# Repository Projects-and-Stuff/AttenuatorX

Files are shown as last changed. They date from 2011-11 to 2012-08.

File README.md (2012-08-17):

# AttenuatorX and AttenuatorXLE #
#### Wide-Band, Large Attenuation, Medium Power, Digitally Adjustable RF Attenuators ####

This project grew out of dissatisfaction for products currently on the market. As part of my job as a Radar Technician, I needed an attenuator that could handle up to around 40 dBm, provide a variety of attenuation levels, and operate over a large frequency spectrum. The only devices I found that met these needs cost over $2000, and are adjusted physically over 1 dB increments. I thought I could do better, so I started working on doing just that. Please feel free to join me if you're interested by forking my project and requesting a merge for any improvements you add.

---

**AttenuatorXLE** is a low-cost Digitally adjustable attenuator which will be the first of two devices developed. It will offer the following preliminary specifications:

* 10 to 41 dB Attenuation in 0.5 dB Steps
* 50 MHz to 3 GHz Operation
* Up to 36 dBm Input Power

---

**AttenuatorX** is a low-cost Digitally adjustable attenuator which will be the first of two devices developed. It will offer the following preliminary specifications:

* 10 to 95 dB Attenuation in 0.5 dB Steps
* 50 MHz to 3 GHz Operation
* Up to 45 dBm Input Power

---

*File Structure*

* ./AttenuatorX/ --> Kicad Project for AttenuatorX RF Hardware
* ./AttenuatorXLE/ --> Kicad Project for AttenuatorXLE RF Hardware
* ./AttenuatorX Controller/ --> Kicad Project Controller for both RF Boards
* ./Firmware/ --> Firmware for both projects (Written in C Utilizing AVR Studio 5 and AVRGCC)
* ./Notes/ --> Project Notes, BOM, and Research on Attenuation and attenuators

---

Additional information, research, and notes can be found at http://www.projectsandstuff.com, or email us at support@projectsandstuff.com

Let us know if you fork and make improvements. We'd be glad to consider merges that improve this project.

---

UPDATES:
All updates can be found in the Project Log, within the Notes folder.

---

CURRENT AUTHORS:

> [Jack Linke](http://www.jacklinke.com)
jacklinke@gmail.com

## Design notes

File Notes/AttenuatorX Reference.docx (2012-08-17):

Projects and Stuff

AttenuatorX

In-Depth Reference

# Overview and Objectives

# Assemble

## Part List

## Tools Required

## Constructing it

# Operate

# Mod

# Buy

# Discuss

# Schematics

# Source Code

## Source Code Overview

## Libraries Used

## Functional Description

Glossary

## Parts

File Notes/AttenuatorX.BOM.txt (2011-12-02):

\\\\\\\\\\\\\\\\\\\\\\\\\\\\\\\\\
/////////////////////////////////
\\\\\\\\\\\\\\\\\\\\\\\\\\\\\\\\\
Bill of Materials for AttenuatorX
/////////////////////////////////
\\\\\\\\\\\\\\\\\\\\\\\\\\\\\\\\\
/////////////////////////////////

SPDT RF Switches

SKY13268-344
http://search.digikey.com/us/en/products/SKY13268-344LF/863-1047-1-ND/2052179
Freq Range: 300kHz-3GHz
Max Input Power: 37.8dBm (6 W)
Insertion Loss: 0.4dB
Isolation: 25dB
Qty: 
U/P: $0.53
T/P: $

RF3025
http://www.rfmw.com/ProductDetail/RF3025/392839
RF Switch, SPDT
Frequency Min: 0.01 GHz 
Frequency Max: 6 GHz 
Insertion Loss Range: 0.5 dB 
Isolation Range: 58 dB 
Power Rating: 27 dBm (0.5 W)
U/P: $2.00 (x25)

FMS2031-001
http://www.rfmw.com/ProductDetail/FMS2031001/319867/
https://estore.rfmd.com/RFMD_Onlinestore/Products/RFMD+Parts/PID-P_FMS2031-001.aspx?DC=25
10W GaAs pHEMT SPDT Switch
Frequency Range (Min) (MHz):  0 
Frequency Range (Max) (MHz):  6000 
Insertion Loss (dB):  0.5 
Isolation (dB):  32 
Max Power: 39-41 dBm (7.9-12.5 W)
U/P: 25 @ $3.03 EA

SP4T RF Switches

PE42641MLIBB-Z
http://search.digikey.com/us/en/products/PE42641MLIBB-Z/1046-1013-1-ND/2614517
Freq Range: 0-3 GHz
Max Input Power: 38dBm (6.3 W)
Insertion Loss: 0.45dBm
Isolation: 43dB
Qty: 
U/P: $2.77
T/P: $

Step Attenuator Chain:

TQP4M9072
http://www.mouser.com/ProductDetail/TriQuint-Semiconductor/TQP4M9072/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
Freq Range: 0-4GHz
LSB: 0.5dB
Max Input Power: 28dBm (0.6 W)
Insertion Loss: 1.5dB
Accuracy: 0.3 + 3%
Max Attenuation: 31.5dB
Qty: 
U/P: $4.18
T/P: $

-------------------

HMC629LP4 / 629LP4E
http://www.hittite.com/products/view.html/view/HMC629LP4
http://www.hittite.com/shop/product.php?productid=1403
Freq Range: DC-6GHz
LSB: 3 dB
Max Attenuation: 45 dB
Input Power: 28 dBm (0.6 W)
Insertion Loss DC - 6: 2.5 dB
Accuracy: 0.50 + 5% of Atten. Setting
$9.75 OR $7.50

Fixed Attenuators:

33-1001-10.00
NO DATASHEET (requested 20111105)
http://www.rfmw.com/ProductDetail/3310011000/302627
Attenuator, Fixed
Frequency Min: 0 GHz 
Frequency Max: 4 GHz 
dB Value: 10 dB 
Power Handling: 20 W (43 dBm)
U/P: $16.98

D10AA5Z4
http://www.rell.com/Pages/Product-Details.aspx?productId=728179
Power 7 W (38.5 dBm)
Attenuation 3 dB
Frequency Max 3000 MHz
$4.34

D10AA3Z4
http://www.rell.com/Pages/Product-Details.aspx?productId=728176
Power 7 W (38.5 dBm)
Attenuation 3 dB
Frequency Max 3000 MHz
$4.34

83A399506.00F
NO DATASHEET (Requested 20111105)
http://www.rfmw.com/ProductDetail/83A39950600F/325214
Attenuator, Fixed
Frequency Min: 0 GHz 
Frequency Max: 3 GHz 
dB Value: 6 dB 
Power Handling: 5 W (37 dBm)
U/P: $12.47

ATN3590-XX
Fixed Attenuators 2W (33 dBm)
http://www.rfmw.com/Paw.aspx?type=330
Freq Range: 0-40 GHz
Attenuation: 1-40 dB
U/P: $3.00-$3.25

Need medium power 1 dB (Rated for XX W) or 2 dB (Rated for XX W) attenuators for the front end.

RF Detector:

LT5534
http://search.digikey.com/us/en/products/LT5534ESC6%23TRMPBF/LT5534ESC6%23TRMPBFCT-ND/962666
Input Range: -63dBm to -3dBm
Frequency: 50MHz ~ 3GHz
Qty: 
U/P: $10.30
T/P: $

CONN FMALE-ON-BRD 6POS VERT T/H
Connector for Encoders
P/N: 7-215079-6
http://search.digikey.com/us/en/products/7-215079-6/A30729CT-ND/740377
Pitch 0.100" (2.54mm)
Qty: 
U/P: $1.33
T/P: $

ENCODER OPT 32PPR IP65 5" CABLE
C14D32P-B3A
Quadrature Encoder with pushbutton
http://search.digikey.com/us/en/products/C14D32P-B3A/102-2034-ND/2193096
Encoder Type Optical
Voltage - Supply 5VDC
Pulses per Revolution 32
Actuator Type 1/4" Dia Flatted End
Detent Yes
Built in Switch Yes
Qty: 
U/P: $17.78
T/P: $

Long Shaft Rotary Encoder
ENCODER 11MM ROTARY SW TOP ADJ
EN11-HSM1BF20
http://search.digikey.com/us/en/products/EN11-HSM1BF20/987-1398-ND/2620667
Actuator Type: 6mm Dia Flatted End
Detent: Yes
Built in Switch: Yes
Qty: 
U/P: $1.35
T/P: $

Short Shaft Rotary Encoder
ENCODER 11MM ROTARY SW TOP ADJ
EN11-HSM1AF15
http://search.digikey.com/us/en/products/EN11-HSM1AF15/987-1188-ND/2408766
Actuator Type: 6mm Dia Flatted End
Detent: Yes
Built in Switch: Yes
Qty: 
U/P: $1.35
T/P: $

KNOB PLASTIC 1/4" DIA BLACK
Knob for encoders (can I find a better one?)
http://search.digikey.com/us/en/products/11K5014-KCNB/GH7339-ND/1534744
Qty: 
U/P: $0.65
T/P: $

BOX HANDHELD TG 4.92 X 3.15 X 1.84"
Project Enclosure
P/N: 270102110
http://search.digikey.com/scripts/dksearch/dksus.dll?vendor=0&keywords=27010211&stock=1
http://www.rose-bopla.com/Prod_Pgs/Handhelds/Prod_04_TG_130_Handheld.htm
Features Battery Door, PCB Supports
Qty: 1
U/P: $11.58
T/P: $11.58

CONN SOCKET BNC R/A 50 OHM PCB
BNC Connectors
P/N: 1-1337543-0
http://search.digikey.com/us/en/products/1-1337543-0/A97553-ND/1755940
Impedance 50 Ohm
Mounting Type Through Hole, Right Angle 
Fastening Type Bayonet Lock
Frequency - Max 4GHz
Qty: 2
U/P: $2.30
T/P: $4.60

SNAPS 9V 6" LEADS I-STYLE
9V Battery Clip
Part Number: BS6I
http://search.digikey.com/us/en/products/BS6I/BS6I-ND/32055
Qty: 1
U/P: $0.53
T/P: $0.53

LCD COG CHAR 2X16 TRANSFL
LCD (Outline L x W x H	54.70mm X 25.30mm X 5.00mm)
http://search.digikey.com/us/en/products/NHD-C0216AZ-FSW-GBW/NHD-C0216AZ-FSW-GBW-ND/2165869
Qty: 1
U/P: $10.11
T/P: $10.11

///// Trimmers for possible alignment attenuator \\\\\

TRIMMER 200 OHM 0.25W SMD
Trimmer/Potentiometer for alignment of attenuation to attenuators
P/N: SM-42TW201
http://search.digikey.com/us/en/products/SM-42TW201/SM-42TW201CT-ND/1632393
Resistance (Ohms): 200
Power (Watts): 0.25W, 1/4W
Number of Turns: 11 
Adjustment Type Top Adjustment
Qty: 
U/P: $2.79
T/P: $

TRIMMER 20 OHM 0.25W SMD
Trimmer/Potentiometer for alignment of attenuation to RF detector
P/N: 3269W-1-200LF
http://search.digikey.com/us/en/products/3269W-1-200LF/3269W-1-200LF-ND/1211542
Resistance (Ohms): 20
Power (Watts): 0.25W, 1/4W
Number of Turns: 12
Adjustment Type Top Adjustment
Qty: 
U/P: $5.64
T/P: $

TRIMMER 500 OHM 0.25W SMD
Trimmer/Potentiometer for alignment of attenuation to RF detector
P/N: SM-42TW501
http://search.digikey.com/us/en/products/SM-42TW501/SM-42TW501CT-ND/1632394
Resistance (Ohms): 500
Power (Watts): 0.25W, 1/4W
Number of Turns: 11 
Adjustment Type Top Adjustment
Qty: 
U/P: $2.79
T/P: $

///// End Trimmers \\\\\

RES 5.1K OHM 1/4W 5% 1206 SMD (3.20mm x 1.60mm)
5.1 KOhm External Pull-up Resistors for Encoder
RMCF1206JT5K10
http://search.digikey.com/us/en/products/RMCF1206JT5K10/RMCF1206JT5K10CT-ND/1942798
Qty: 1
U/P: $0.05
T/P: $0.05

CAP CER 0.3PF 50V 0603 (1.60mm x 0.84mm)
0.3 pF ±0.05pF coupling capacitor for RF Detector (to obtain ~20db loss) (qty 1)
ML03510R3AAT2A
http://search.digikey.com/us/en/products/ML03510R3AAT2A/478-6725-1-ND/2694239
Qty: 1
U/P: $0.88
T/P: $0.88

RES PREC 100 OHM 333MW .1% 1206 (3.20mm x 1.60mm)
100 Ohm +/-5% coupling resistor for RF Detector (to obtain ~20db loss)
PFC-W1206LF-03-1000-B-1059
http://search.digikey.com/us/en/products/PFC-W1206LF-03-1000-B-1059/989-1154-1-ND/2407974
Qty: 1
U/P: $0.65
T/P: $0.65

CAP CER 0.1UF 50V 10% X7R 1206
0.1 uF Ceramic Bypass Capacitor for Digital Circuitry
12065C104KAT2A
http://search.digikey.com/us/en/products/12065C104KAT2A/478-1556-1-ND/564588
Qty: 20
U/P: $0.077
T/P: $1.54

Bulk Bypass Capacitors
CAP CER 10UF 25V Y5V 1206
C3216Y5V1E106Z
http://search.digikey.com/us/en/products/C3216Y5V1E106Z/445-3469-1-ND/1801568
Qty: Multiple
U/P: $0.36
T/P: $

CAP CERAMIC 100PF 50V NP0 1206
100 pF capacitors for SPDT RF Switch DC Blocking (qty 3)
C1206C101J5GACTU
http://search.digikey.com/us/en/products/C1206C101J5GACTU/399-1205-1-ND/411480
Qty: 3
U/P: $0.31
T/P: $0.93

RES TF 15 OHM 5% 0.25W 1206
15 Ohm Pull-up resistor for TQP4M9072 Attenuator
RMCF1206JT15R0
http://search.digikey.com/us/en/products/RMCF1206JT15R0/RMCF1206JT15R0CT-ND/2418885
Qty: 1
U/P: $0.05
T/P: $0.05

CAP CERAMIC 1000PF 50V NP0 1206
1 nF coupling capacitor for TQP4M9072 Attenuator (qty 2)
C1206C102J5GACTU
http://search.digikey.com/us/en/products/C1206C102J5GACTU/399-1218-1-ND/411493
Qty: 2
U/P: $0.33
T/P: $0.66

CAP CER 330PF 630V C0G 5% 1206
330 pF Bypass Capacitor for TQP4M9072 Attenuator (qty 4)
C3216C0G2J331J
http://search.digikey.com/us/en/products/C3216C0G2J331J/445-2339-1-ND/789848
Qty: 4
U/P: $0.36
T/P: $1.44

RES 33 OHM 1/4W 5% 1206 SMD
33 Ohm Limiting resistors for TQP4M9072 Attenuator
RMCF1206JT33R0
http://search.digikey.com/us/en/products/RMCF1206JT33R0/RMCF1206JT33R0CT-ND/1942758
Qty: 3
U/P: $0.05
T/P: $0.15

CAP CERAMIC 47PF 50V NP0 1206
47 pF Bypass Capacitor for TQP4M9072 Attenuator (qty 3)
C1206C470J5GACTU
http://search.digikey.com/us/en/products/C1206C470J5GACTU/399-1201-1-ND/411476
Qty: 3
U/P: $0.31
T/P: $0.93

IC REG LDO 300MA 5.0V SOT23-5
5V Regulator
MCP1802T-5002I/OT
http://search.digikey.com/scripts/DkSearch/dksus.dll?Detail&name=MCP1802T-5002I/OTCT-ND
Qty: 1
U/P: $0.65
T/P: $0.65

ATMEGA48/88/168/328 (A,P,PA)
Atmel AVR Microcontroller (ATMEGA168A) IC MCU AVR 16K FLASH 32TQFP
http://search.digikey.com/us/en/products/ATMEGA168A-AU/ATMEGA168A-AU-ND/2271188
Qty: 1
U/P: $3.23
T/P: $3.23

20MHz Crystal
9C-20.000MEEJ-T
http://search.digikey.com/scripts/DkSearch/dksus.dll?Detail&name=887-1278-1-ND
Qty: 1
U/P: $0.68
T/P: $0.68

Crystal Load Caps
CAP CER 12PF 50V NP0 1206
C1206C120J5GACTU
http://search.digikey.com/us/en/products/C1206C120J5GACTU/399-1193-1-ND/411468
Qty: 2
U/P: $0.31
T/P: $0.62

uC Reset Resistor
RES 4.7K OHM 1/4W 5% 1206 SMD
RMCF1206JT4K70
http://search.digikey.com/scripts/DkSearch/dksus.dll?Detail&name=RMCF1206JT4K70CT-ND
Qty: 1
U/P: $0.05
T/P: $0.05

EMI/RFI Shielding
Super Shield Conductive Coating
http://www.mgchemicals.com/products/841.html
Qty: 1
U/P: ~$35
T/P: ~$35

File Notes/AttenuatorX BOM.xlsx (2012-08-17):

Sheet: Electronics
Bill of Materials - AttenuatorX - Electronics |  |  |  |  |  |  |  |  | # of boards goal: | 1000
Projects and Stuff LLC - http://www.projectsandstuff.com
Total BOM Parts Cost: | $0.00
Description | Mfg Part # | Package | Default Supplier | Supplier On Hand | Qty per board | Total Qty Needed | Price per part at Qty | Total Price | Notes | Part References
 |  |  |  |  |  | 0 |  | $0.00
 |  |  |  |  |  | 0 |  | $0.00
 |  |  |  |  |  | 0 |  | $0.00
 |  |  |  |  |  | 0 |  | $0.00
 |  |  |  |  |  | 0 |  | $0.00
 |  |  |  |  |  | 0 |  | $0.00
 |  |  |  |  |  | 0 |  | $0.00
 |  |  |  |  |  | 0 |  | $0.00
 |  |  |  |  |  | 0 |  | $0.00
 |  |  |  |  |  | 0 |  | $0.00
 |  |  |  |  |  | 0 |  | $0.00
 |  |  |  |  |  | 0 |  | $0.00
 |  |  |  |  |  | 0 |  | $0.00
 |  |  |  |  |  | 0 |  | $0.00
 |  |  |  |  |  | 0 |  | $0.00
 |  |  |  |  |  | 0 |  | $0.00
 |  |  |  |  |  | 0 |  | $0.00
 |  |  |  |  |  | 0 |  | $0.00
 |  |  |  |  |  | 0 |  | $0.00
 |  |  |  |  |  | 0 |  | $0.00
 |  |  |  |  |  | 0 |  | $0.00
 |  |  |  |  |  | 0 |  | $0.00
 |  |  |  |  |  | 0 |  | $0.00
 |  |  |  |  |  | 0 |  | $0.00
 |  |  |  |  |  | 0 |  | $0.00
 |  |  |  |  |  | 0 |  | $0.00
 |  |  |  |  |  | 0 |  | $0.00
 |  |  |  |  |  | 0 |  | $0.00
 |  |  |  |  |  | 0 |  | $0.00
 |  |  |  |  |  | 0 |  | $0.00
 |  |  |  |  |  | 0 |  | $0.00
 |  |  |  |  |  | 0 |  | $0.00
 |  |  |  |  |  | 0 |  | $0.00
 |  |  |  |  |  | 0 |  | $0.00
 |  |  |  |  |  | 0 |  | $0.00
 |  |  |  |  |  | 0 |  | $0.00
 |  |  |  |  |  | 0 |  | $0.00
 |  |  |  |  |  | 0 |  | $0.00
 |  |  |  |  |  | 0 |  | $0.00
 |  |  |  |  |  | 0 |  | $0.00
 |  |  |  |  |  | 0 |  | $0.00
 |  |  |  |  |  | 0 |  | $0.00
 |  |  |  |  |  | 0 |  | $0.00
 |  |  |  |  |  | 0 |  | $0.00
 |  |  |  |  |  | 0 |  | $0.00
 |  |  |  |  |  | 0 |  | $0.00
 |  |  |  |  |  | 0 |  | $0.00
 |  |  |  |  |  | 0 |  | $0.00
 |  |  |  |  |  | 0 |  | $0.00
 |  |  |  |  |  | 0 |  | $0.00
 |  |  |  |  |  | 0 |  | $0.00
 |  |  |  |  |  | 0 |  | $0.00
 |  |  |  |  |  | 0 |  | $0.00
 |  |  |  |  |  | 0 |  | $0.00
 |  |  |  |  |  | 0 |  | $0.00
 |  |  |  |  |  | 0 |  | $0.00
 |  |  |  |  |  | 0 |  | $0.00
 |  |  |  |  |  | 0 |  | $0.00
 |  |  |  |  |  | 0 |  | $0.00
 |  |  |  |  |  | 0 |  | $0.00
 |  |  |  |  |  | 0 |  | $0.00
 |  |  |  |  |  | 0 |  | $0.00
 |  |  |  |  |  | 0 |  | $0.00
 |  |  |  |  |  | 0 |  | $0.00
 |  |  |  |  |  | 0 |  | $0.00
 |  |  |  |  |  | 0 |  | $0.00
 |  |  |  |  |  | 0 |  | $0.00
 |  |  |  |  |  | 0 |  | $0.00
 |  |  |  |  |  | 0 |  | $0.00
 |  |  |  |  |  | 0 |  | $0.00
 |  |  |  |  |  | 0 |  | $0.00
 |  |  |  |  |  | 0 |  | $0.00
 |  |  |  |  |  | 0 |  | $0.00
 |  |  |  |  |  | 0 |  | $0.00
 |  |  |  |  |  | 0 |  | $0.00
 |  |  |  |  |  | 0 |  | $0.00
 |  |  |  |  |  | 0 |  | $0.00
 |  |  |  |  |  | 0 |  | $0.00
 |  |  |  |  |  | 0 |  | $0.00
 |  |  |  |  |  | 0 |  | $0.00
 |  |  |  |  |  | 0 |  | $0.00
 |  |  |  |  |  | 0 |  | $0.00
 |  |  |  |  |  | 0 |  | $0.00
 |  |  |  |  |  | 0 |  | $0.00
 |  |  |  |  |  | 0 |  | $0.00
 |  |  |  |  |  | 0 |  | $0.00
 |  |  |  |  |  | 0 |  | $0.00
 |  |  |  |  |  | 0 |  | $0.00
 |  |  |  |  |  | 0 |  | $0.00
 |  |  |  |  |  | 0 |  | $0.00
 |  |  |  |  |  | 0 |  | $0.00
 |  |  |  |  |  | 0 |  | $0.00
 |  |  |  |  |  | 0 |  | $0.00
 |  |  |  |  |  | 0 |  | $0.00
 |  |  |  |  |  | 0 |  | $0.00
 |  |  |  |  |  | 0 |  | $0.00
 |  |  |  |  |  | 0 |  | $0.00
 |  |  |  |  |  | 0 |  | $0.00
 |  |  |  |  |  | 0 |  | $0.00
 |  |  |  |  |  | 0 |  | $0.00
 |  |  |  |  |  | 0 |  | $0.00
 |  |  |  |  |  | 0 |  | $0.00
 |  |  |  |  |  | 0 |  | $0.00
 |  |  |  |  |  | 0 |  | $0.00
 |  |  |  |  |  | 0 |  | $0.00
 |  |  |  |  |  | 0 |  | $0.00
 |  |  |  |  |  | 0 |  | $0.00
 |  |  |  |  |  | 0 |  | $0.00
 |  |  |  |  |  | 0 |  | $0.00
 |  |  |  |  |  | 0 |  | $0.00
 |  |  |  |  |  | 0 |  | $0.00
 |  |  |  |  |  | 0 |  | $0.00
 |  |  |  |  |  | 0 |  | $0.00
 |  |  |  |  |  | 0 |  | $0.00
 |  |  |  |  |  | 0 |  | $0.00
 |  |  |  |  |  | 0 |  | $0.00
 |  |  |  |  |  | 0 |  | $0.00
 |  |  |  |  |  | 0 |  | $0.00
 |  |  |  |  |  | 0 |  | $0.00
 |  |  |  |  |  | 0 |  | $0.00
 |  |  |  |  |  | 0 |  | $0.00
 |  |  |  |  |  | 0 |  | $0.00
 |  |  |  |  |  | 0 |  | $0.00
 |  |  |  |  |  | 0 |  | $0.00
 |  |  |  |  |  | 0 |  | $0.00
 |  |  |  |  |  | 0 |  | $0.00
 |  |  |  |  |  | 0 |  | $0.00
 |  |  |  |  |  | 0 |  | $0.00
 |  |  |  |  |  | 0 |  | $0.00
 |  |  |  |  |  | 0 |  | $0.00
 |  |  |  |  |  | 0 |  | $0.00
 |  |  |  |  |  | 0 |  | $0.00
 |  |  |  |  |  | 0 |  | $0.00
 |  |  |  |  |  | 0 |  | $0.00
 |  |  |  |  |  | 0 |  | $0.00
 |  |  |  |  |  | 0 |  | $0.00
 |  |  |  |  |  | 0 |  | $0.00
 |  |  |  |  |  | 0 |  | $0.00
 |  |  |  |  |  | 0 |  | $0.00
 |  |  |  |  |  | 0 |  | $0.00
 |  |  |  |  |  | 0 |  | $0.00
 |  |  |  |  |  | 0 |  | $0.00
 |  |  |  |  |  | 0 |  | $0.00
 |  |  |  |  |  | 0 |  | $0.00
 |  |  |  |  |  | 0 |  | $0.00
 |  |  |  |  |  | 0 |  | $0.00
 |  |  |  |  |  | 0 |  | $0.00
 |  |  |  |  |  | 0 |  | $0.00
 |  |  |  |  |  | 0 |  | $0.00
 |  |  |  |  |  | 0 |  | $0.00
 |  |  |  |  |  | 0 |  | $0.00
 |  |  |  |  |  | 0 |  | $0.00
 |  |  |  |  |  | 0 |  | $0.00
 |  |  |  |  |  | 0 |  | $0.00
 |  |  |  |  |  | 0 |  | $0.00
 |  |  |  |  |  | 0 |  | $0.00
 |  |  |  |  |  | 0 |  | $0.00
 |  |  |  |  |  | 0 |  | $0.00
 |  |  |  |  |  | 0 |  | $0.00
 |  |  |  |  |  | 0 |  | $0.00
 |  |  |  |  |  | 0 |  | $0.00
 |  |  |  |  |  | 0 |  | $0.00
 |  |  |  |  |  | 0 |  | $0.00
 |  |  |  |  |  | 0 |  | $0.00
 |  |  |  |  |  | 0 |  | $0.00
 |  |  |  |  |  | 0 |  | $0.00
 |  |  |  |  |  | 0 |  | $0.00
 |  |  |  |  |  | 0 |  | $0.00
 |  |  |  |  |  | 0 |  | $0.00
 |  |  |  |  |  | 0 |  | $0.00
 |  |  |  |  |  | 0 |  | $0.00
 |  |  |  |  |  | 0 |  | $0.00
 |  |  |  |  |  | 0 |  | $0.00
 |  |  |  |  |  | 0 |  | $0.00
 |  |  |  |  |  | 0 |  | $0.00
 |  |  |  |  |  | 0 |  | $0.00
 |  |  |  |  |  | 0 |  | $0.00
 |  |  |  |  |  | 0 |  | $0.00
 |  |  |  |  |  | 0 |  | $0.00
 |  |  |  |  |  | 0 |  | $0.00
 |  |  |  |  |  | 0 |  | $0.00
 |  |  |  |  |  | 0 |  | $0.00
 |  |  |  |  |  | 0 |  | $0.00
 |  |  |  |  |  | 0 |  | $0.00
 |  |  |  |  |  | 0 |  | $0.00
 |  |  |  |  |  | 0 |  | $0.00
 |  |  |  |  |  | 0 |  | $0.00
 |  |  |  |  |  | 0 |  | $0.00
 |  |  |  |  |  | 0 |  | $0.00
 |  |  |  |  |  | 0 |  | $0.00
 |  |  |  |  |  | 0 |  | $0.00
 |  |  |  |  |  | 0 |  | $0.00
 |  |  |  |  |  | 0 |  | $0.00
 |  |  |  |  |  | 0 |  | $0.00
 |  |  |  |  |  | 0 |  | $0.00

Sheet: Other
Bill of Materials - AttenuatorX - Other |  |  |  |  |  |  |  | # of boards goal: | 1000
Projects and Stuff LLC - http://www.projectsandstuff.com
Total BOM Parts Cost: | $0.00
Description | Mfg Part # | Default Supplier | Supplier On Hand | Qty per board | Total Qty Needed | Price per part at Qty | Total Price | Notes | Part References
 |  |  |  |  | 0 |  | $0.00
 |  |  |  |  | 0 |  | $0.00
 |  |  |  |  | 0 |  | $0.00
 |  |  |  |  | 0 |  | $0.00
 |  |  |  |  | 0 |  | $0.00
 |  |  |  |  | 0 |  | $0.00
 |  |  |  |  | 0 |  | $0.00
 |  |  |  |  | 0 |  | $0.00
 |  |  |  |  | 0 |  | $0.00
 |  |  |  |  | 0 |  | $0.00
 |  |  |  |  | 0 |  | $0.00
 |  |  |  |  | 0 |  | $0.00
 |  |  |  |  | 0 |  | $0.00
 |  |  |  |  | 0 |  | $0.00
 |  |  |  |  | 0 |  | $0.00
 |  |  |  |  | 0 |  | $0.00
 |  |  |  |  | 0 |  | $0.00
 |  |  |  |  | 0 |  | $0.00
 |  |  |  |  | 0 |  | $0.00
 |  |  |  |  | 0 |  | $0.00
 |  |  |  |  | 0 |  | $0.00
 |  |  |  |  | 0 |  | $0.00
 |  |  |  |  | 0 |  | $0.00
 |  |  |  |  | 0 |  | $0.00
 |  |  |  |  | 0 |  | $0.00
 |  |  |  |  | 0 |  | $0.00
 |  |  |  |  | 0 |  | $0.00
 |  |  |  |  | 0 |  | $0.00
 |  |  |  |  | 0 |  | $0.00
 |  |  |  |  | 0 |  | $0.00
 |  |  |  |  | 0 |  | $0.00
 |  |  |  |  | 0 |  | $0.00
 |  |  |  |  | 0 |  | $0.00
 |  |  |  |  | 0 |  | $0.00
 |  |  |  |  | 0 |  | $0.00
 |  |  |  |  | 0 |  | $0.00
 |  |  |  |  | 0 |  | $0.00
 |  |  |  |  | 0 |  | $0.00
 |  |  |  |  | 0 |  | $0.00
 |  |  |  |  | 0 |  | $0.00
 |  |  |  |  | 0 |  | $0.00
 |  |  |  |  | 0 |  | $0.00
 |  |  |  |  | 0 |  | $0.00
 |  |  |  |  | 0 |  | $0.00
 |  |  |  |  | 0 |  | $0.00
 |  |  |  |  | 0 |  | $0.00
 |  |  |  |  | 0 |  | $0.00
 |  |  |  |  | 0 |  | $0.00
 |  |  |  |  | 0 |  | $0.00
 |  |  |  |  | 0 |  | $0.00
 |  |  |  |  | 0 |  | $0.00
 |  |  |  |  | 0 |  | $0.00
 |  |  |  |  | 0 |  | $0.00
 |  |  |  |  | 0 |  | $0.00
 |  |  |  |  | 0 |  | $0.00
 |  |  |  |  | 0 |  | $0.00
 |  |  |  |  | 0 |  | $0.00
 |  |  |  |  | 0 |  | $0.00
 |  |  |  |  | 0 |  | $0.00
 |  |  |  |  | 0 |  | $0.00
 |  |  |  |  | 0 |  | $0.00
 |  |  |  |  | 0 |  | $0.00
 |  |  |  |  | 0 |  | $0.00
 |  |  |  |  | 0 |  | $0.00
 |  |  |  |  | 0 |  | $0.00
 |  |  |  |  | 0 |  | $0.00
 |  |  |  |  | 0 |  | $0.00
 |  |  |  |  | 0 |  | $0.00
 |  |  |  |  | 0 |  | $0.00
 |  |  |  |  | 0 |  | $0.00
 |  |  |  |  | 0 |  | $0.00
 |  |  |  |  | 0 |  | $0.00
 |  |  |  |  | 0 |  | $0.00
 |  |  |  |  | 0 |  | $0.00
 |  |  |  |  | 0 |  | $0.00
 |  |  |  |  | 0 |  | $0.00
 |  |  |  |  | 0 |  | $0.00
 |  |  |  |  | 0 |  | $0.00
 |  |  |  |  | 0 |  | $0.00
 |  |  |  |  | 0 |  | $0.00
 |  |  |  |  | 0 |  | $0.00
 |  |  |  |  | 0 |  | $0.00
 |  |  |  |  | 0 |  | $0.00
 |  |  |  |  | 0 |  | $0.00
 |  |  |  |  | 0 |  | $0.00
 |  |  |  |  | 0 |  | $0.00
 |  |  |  |  | 0 |  | $0.00
 |  |  |  |  | 0 |  | $0.00
 |  |  |  |  | 0 |  | $0.00
 |  |  |  |  | 0 |  | $0.00
 |  |  |  |  | 0 |  | $0.00
 |  |  |  |  | 0 |  | $0.00
 |  |  |  |  | 0 |  | $0.00
 |  |  |  |  | 0 |  | $0.00
 |  |  |  |  | 0 |  | $0.00
 |  |  |  |  | 0 |  | $0.00
 |  |  |  |  | 0 |  | $0.00
 |  |  |  |  | 0 |  | $0.00
 |  |  |  |  | 0 |  | $0.00
 |  |  |  |  | 0 |  | $0.00
 |  |  |  |  | 0 |  | $0.00
 |  |  |  |  | 0 |  | $0.00
 |  |  |  |  | 0 |  | $0.00
 |  |  |  |  | 0 |  | $0.00
 |  |  |  |  | 0 |  | $0.00
 |  |  |  |  | 0 |  | $0.00
 |  |  |  |  | 0 |  | $0.00
 |  |  |  |  | 0 |  | $0.00
 |  |  |  |  | 0 |  | $0.00
 |  |  |  |  | 0 |  | $0.00
 |  |  |  |  | 0 |  | $0.00
 |  |  |  |  | 0 |  | $0.00
 |  |  |  |  | 0 |  | $0.00
 |  |  |  |  | 0 |  | $0.00
 |  |  |  |  | 0 |  | $0.00
 |  |  |  |  | 0 |  | $0.00
 |  |  |  |  | 0 |  | $0.00
 |  |  |  |  | 0 |  | $0.00
 |  |  |  |  | 0 |  | $0.00
 |  |  |  |  | 0 |  | $0.00
 |  |  |  |  | 0 |  | $0.00
 |  |  |  |  | 0 |  | $0.00
 |  |  |  |  | 0 |  | $0.00
 |  |  |  |  | 0 |  | $0.00
 |  |  |  |  | 0 |  | $0.00
 |  |  |  |  | 0 |  | $0.00
 |  |  |  |  | 0 |  | $0.00
 |  |  |  |  | 0 |  | $0.00
 |  |  |  |  | 0 |  | $0.00
 |  |  |  |  | 0 |  | $0.00
 |  |  |  |  | 0 |  | $0.00
 |  |  |  |  | 0 |  | $0.00
 |  |  |  |  | 0 |  | $0.00
 |  |  |  |  | 0 |  | $0.00
 |  |  |  |  | 0 |  | $0.00
 |  |  |  |  | 0 |  | $0.00
 |  |  |  |  | 0 |  | $0.00
 |  |  |  |  | 0 |  | $0.00
 |  |  |  |  | 0 |  | $0.00
 |  |  |  |  | 0 |  | $0.00
 |  |  |  |  | 0 |  | $0.00
 |  |  |  |  | 0 |  | $0.00
 |  |  |  |  | 0 |  | $0.00
 |  |  |  |  | 0 |  | $0.00
 |  |  |  |  | 0 |  | $0.00
 |  |  |  |  | 0 |  | $0.00
 |  |  |  |  | 0 |  | $0.00
 |  |  |  |  | 0 |  | $0.00
 |  |  |  |  | 0 |  | $0.00
 |  |  |  |  | 0 |  | $0.00
 |  |  |  |  | 0 |  | $0.00
 |  |  |  |  | 0 |  | $0.00
 |  |  |  |  | 0 |  | $0.00
 |  |  |  |  | 0 |  | $0.00
 |  |  |  |  | 0 |  | $0.00
 |  |  |  |  | 0 |  | $0.00
 |  |  |  |  | 0 |  | $0.00
 |  |  |  |  | 0 |  | $0.00
 |  |  |  |  | 0 |  | $0.00
 |  |  |  |  | 0 |  | $0.00
 |  |  |  |  | 0 |  | $0.00
 |  |  |  |  | 0 |  | $0.00
 |  |  |  |  | 0 |  | $0.00
 |  |  |  |  | 0 |  | $0.00
 |  |  |  |  | 0 |  | $0.00
 |  |  |  |  | 0 |  | $0.00
 |  |  |  |  | 0 |  | $0.00
 |  |  |  |  | 0 |  | $0.00
 |  |  |  |  | 0 |  | $0.00
 |  |  |  |  | 0 |  | $0.00
 |  |  |  |  | 0 |  | $0.00
 |  |  |  |  | 0 |  | $0.00
 |  |  |  |  | 0 |  | $0.00
 |  |  |  |  | 0 |  | $0.00
 |  |  |  |  | 0 |  | $0.00
 |  |  |  |  | 0 |  | $0.00
 |  |  |  |  | 0 |  | $0.00
 |  |  |  |  | 0 |  | $0.00
 |  |  |  |  | 0 |  | $0.00
 |  |  |  |  | 0 |  | $0.00
 |  |  |  |  | 0 |  | $0.00
 |  |  |  |  | 0 |  | $0.00
 |  |  |  |  | 0 |  | $0.00
 |  |  |  |  | 0 |  | $0.00
 |  |  |  |  | 0 |  | $0.00
 |  |  |  |  | 0 |  | $0.00
 |  |  |  |  | 0 |  | $0.00
 |  |  |  |  | 0 |  | $0.00
 |  |  |  |  | 0 |  | $0.00
 |  |  |  |  | 0 |  | $0.00
 |  |  |  |  | 0 |  | $0.00
 |  |  |  |  | 0 |  | $0.00
 |  |  |  |  | 0 |  | $0.00
 |  |  |  |  | 0 |  | $0.00
 |  |  |  |  | 0 |  | $0.00

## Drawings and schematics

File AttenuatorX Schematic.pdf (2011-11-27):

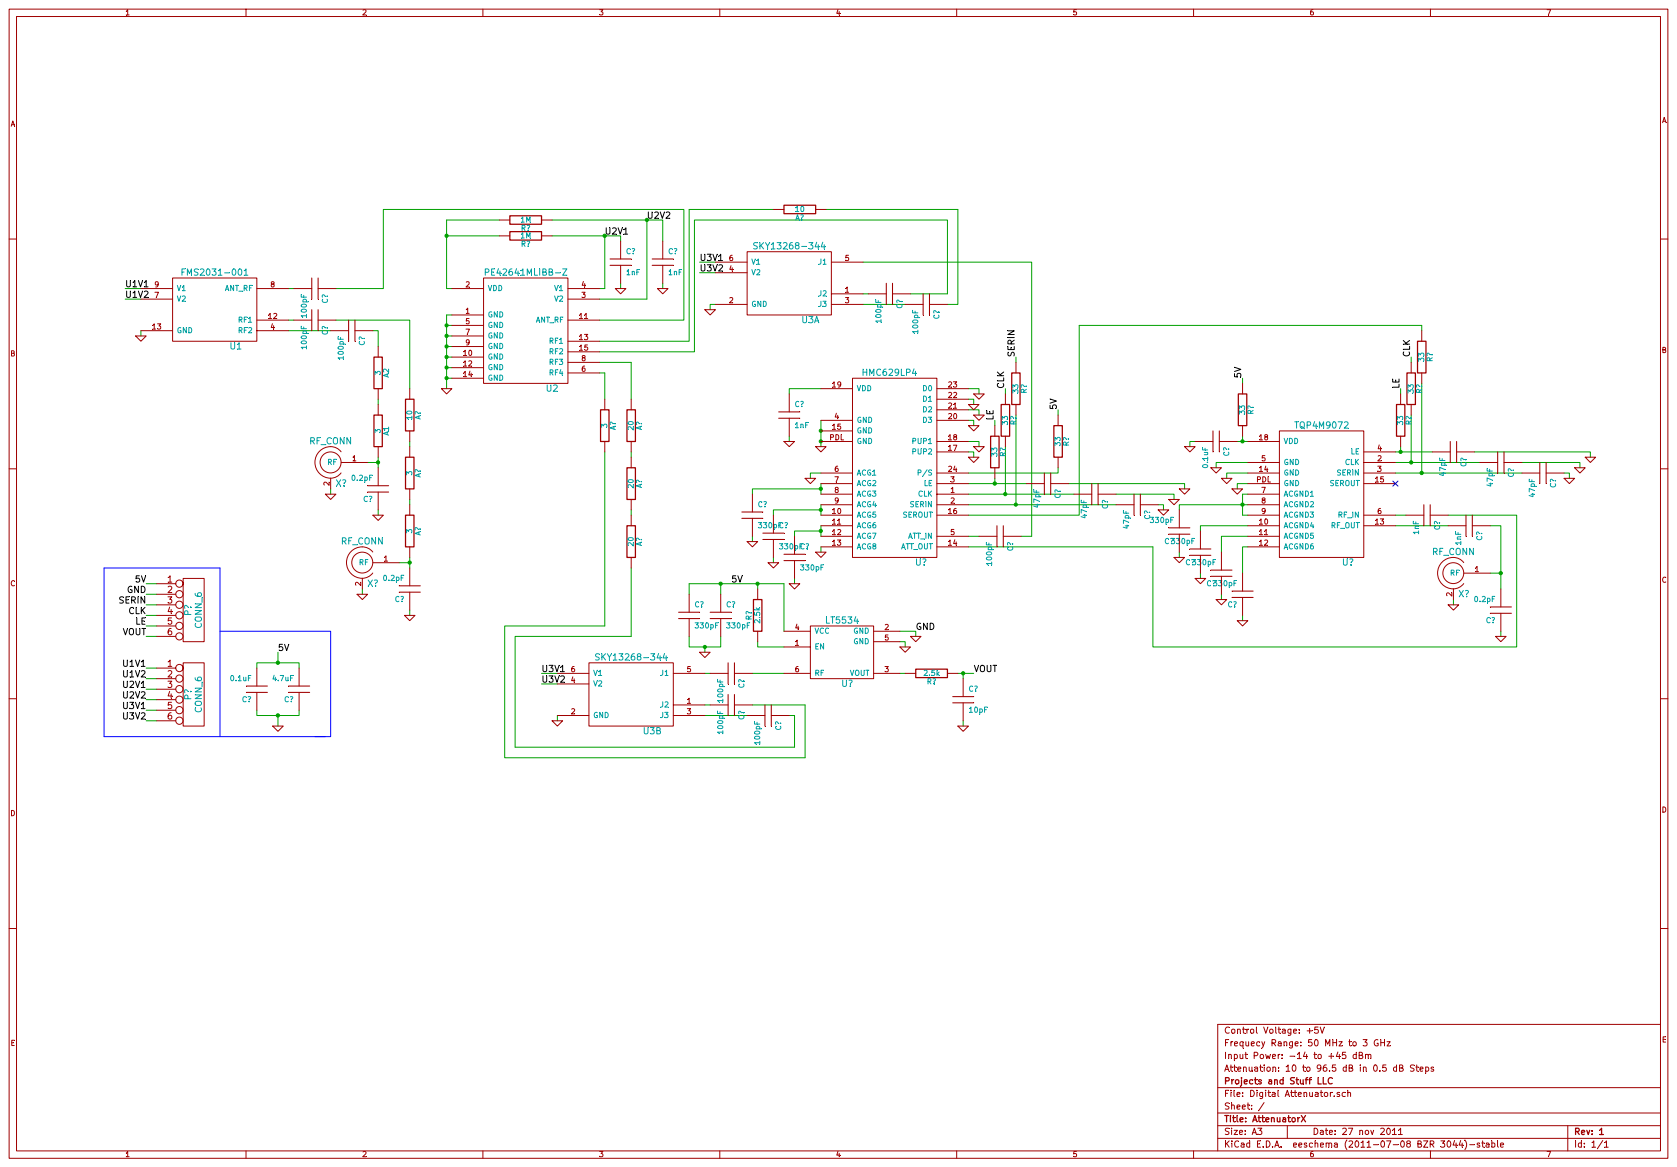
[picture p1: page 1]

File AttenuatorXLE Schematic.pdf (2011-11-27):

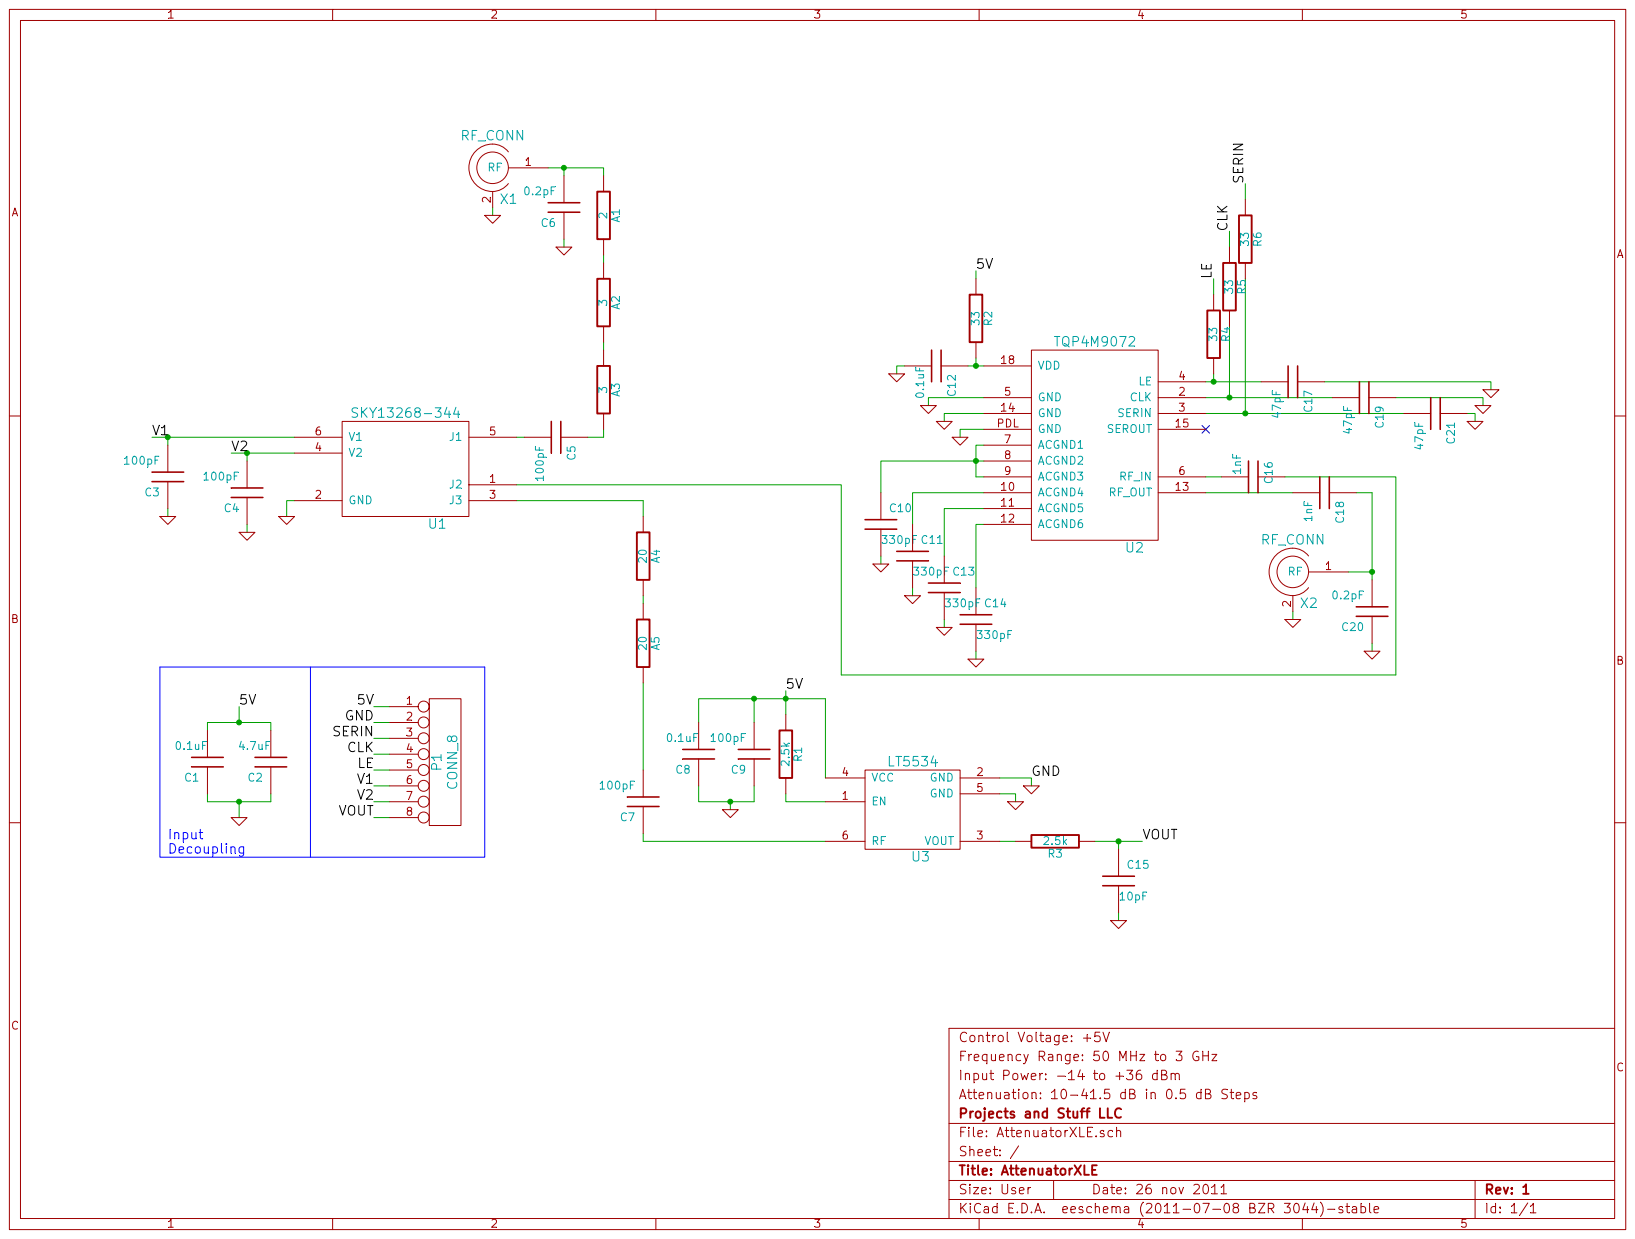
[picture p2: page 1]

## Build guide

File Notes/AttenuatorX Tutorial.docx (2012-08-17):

Projects and Stuff

AttenuatorX

Tutorial

# Overview and Objectives

# Assemble

## Part List

## Tools Required

## Constructing it

# Operate

# Mod

# Buy

# Discuss

Glossary

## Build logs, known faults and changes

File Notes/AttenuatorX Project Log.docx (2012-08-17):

Projects and Stuff

AttenuatorX

Project Log

# Previous

Troubleshooting is a big part of my job as a Radar Technician in the US Marine Corps. Unfortunately, as you probably know if you've worked with electronics for long, good test equipment can often be prohibitively expensive, even for the government. One of the most common aspects of our troubleshooting process is checking Radio and Intermediate frequency signals with a spectrum analyzer. The particular model of analyzer we use has an enormous frequency range up into the tens of gigahertz, but its input power range is limited to about 30dBm. One signal we often look at is supposed to be at 28dBm, very close to the input power limits of the analyzer. If the signal hasn’t been properly attenuated within the system, the output could potentially be above 30dBm. There are several other areas where similar potential damage could occur.

Seeking to prevent this potential damage, I looked for an adjustable attenuator, in order to lower the RF output to a more useable level. I did end up finding a few adjustable attenuators, but I found that most of the attenuators that met my needs cost upwards of $2000.

So I set out to make my own adjustable attenuator with digital control, meeting the following specifications:

Required:

- Operation from 1 to 2GHz (the frequency range most often used in my line of work)

- Protect Spectrum Analyzer in case of very high power (input power should be well over 30dBm, which is equivalent to 1 Watt. Ideally we’ll have an input capability of at least 40dBm, which is equivalent to 10 Watts)

- Wide range of attenuation levels (The commercial attenuator I was looking at operates from 0-70dB, so I want to approach that same range)

- Good accuracy

- Easy to operate

- Easy to calibrate at the user-level using a Laboratory calibrated frequency generator and spectrum analyzer (all of our spectrum analyzers and frequency generators are calibrated regularly)

Optional, but desired:

- Operational at a much wider frequency range. Ideally DC-3GHz

- Should Display at least an approximate input power level

# 2012/08/16

Began updating the project. It’s been stalled for a while. I was making good progress on this while in Afghanistan, but with the transition back to the US, this project dropped to the side. Now I’m ready to revive it, and make this a reality.

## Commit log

2011-11-22 Updating with most current files
    [AttenuatorXLE Control.sch, AttenuatorXLE.sch, Digital Attenuator Controller.sch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]
2011-11-22 Cleaning Structure
    [Digital Attenuator Controller.sch, Digital Attenuator.sch]
2011-11-27 Updated Schematics
    [AttenuatorXLE.sch, Digital Attenuator.sch]
2011-11-27 Updated Structure and Schematics
    [$savepcb.brd, AttenuatorX Controller.sch, AttenuatorX.brd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]
2011-11-27 Removed extraneous files
    [AttenuatorXLE Control.sch, Digital Attenuator Controller.sch, Digital Attenuator.sch]
2011-11-30 Updated BOM and Libraries
    [AttenuatorX Controller.sch, AttenuatorXLE.sch]
2011-11-30 Updated BOM
2011-12-02 Updated BOM, Controller, and Libraries
    [AttenuatorX Controller.sch]
2012-08-17 Reviving project - Updated Documentation in prep for new work
    [AttenuatorX BOM.xlsx]
